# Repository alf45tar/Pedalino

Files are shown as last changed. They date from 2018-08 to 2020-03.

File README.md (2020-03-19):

# Pedalino™ has been superseed by [PedalinoMini™](https://github.com/alf45tar/PedalinoMini).

# Pedalino™ (discontinued)

_I know. You are thinking: "yet another MIDI controller with Arduino"._
_Pedalino™ is something new from any previous DIY projects and even better of commercial alternatives at a fraction of the cost._

>Right now the hardware is just a working well prototype. It will be boxed when the hardware will be frozen.

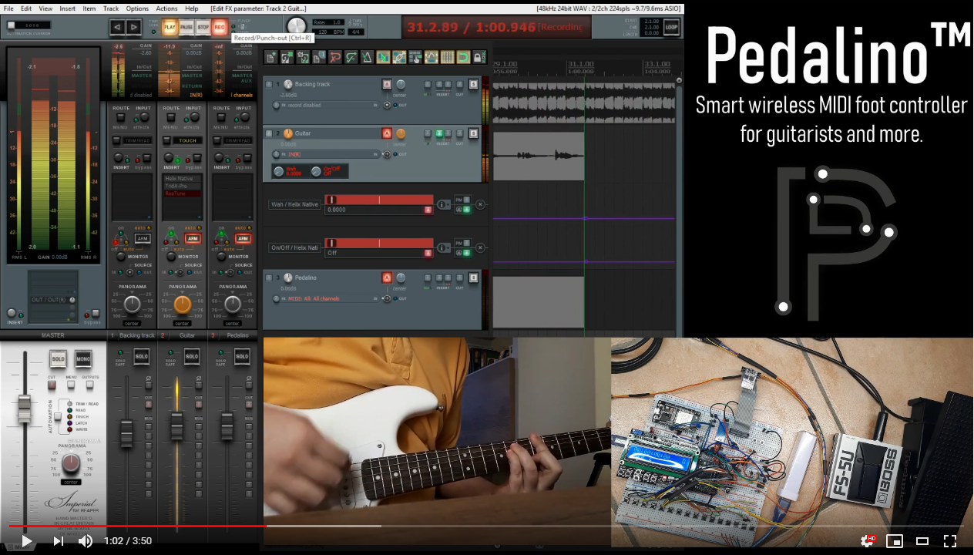
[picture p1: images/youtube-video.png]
(https://youtu.be/pCNSvJ9QiDs)


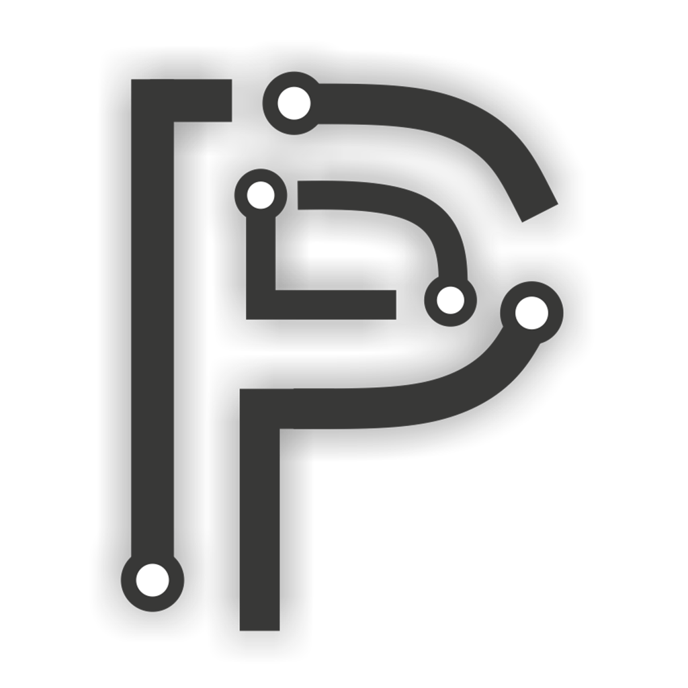
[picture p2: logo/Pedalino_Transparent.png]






Smart wireless MIDI foot controller for guitarists and more.

- Plug-and-play with any MIDI-compatible app on iOS 8 and above as well as OS X Yosemite and above.
- High customizable using iOS or Android app
- 4 MIDI interface (USB, Bluetooth, WiFi, legacy DIN MIDI IN and MIDI OUT connectors)
- No extra drivers to connect Windows, macOS, iOS (iPad/iPhone) and Android
- USB MIDI class-compliant device
- Bluetooth LE MIDI (iOS and macOS compatible)
- Network MIDI (aka AppleMIDI or RTP-MIDI)
- ipMIDI
- Open Sound Control (OSC)
- IEEE 802.11 b/g/n Wi-Fi 2.4 GHZ with WPA/WPA2 authentication
- Bluetooth Low Energy 4.0
- MIDI routing from/to any interface (USB, Bluetooth, WiFi, legacy)
- MIDI clock master and slave
- MIDI Time Code (MTC) master and slave
- OSC to MIDI and vicecersa
- Any number of pedals of any type in any order
- Auto-sensing footswitches and expression pedals
- Modular assembly of easy to find hardware and re-use of open source software libraries

## Applications

- Change preset to your favourite guitar rig
- Hands-free way to control your audio parameters during live performance
- Dramatically expanded audio system parameter control via WiFi, Bluetooth, USB, MIDI or OSC.
- Set your music free with wireless MIDI connectivity
- Bluetooth wireless MIDI adaptor for connecting instruments with MIDI IN/OUT terminals to your iOS devices (iPhone/iPad/iPod Touch) or Mac
- Transform legacy MIDI equipment to USB MIDI class-compliant device
- Transform wired MIDI equipment into wireless MIDI equipment
- Transform legacy MIDI equipment to OSC control surface
- Connect Windows to macOS and iOS devices via AppleMIDI or Bluetooth LE
- Send MIDI messages using an IR remote control from your sofa

## Features

- Support for digital foot switches (momentary or latch), analog expression pedals and jog wheels (rotary encoders)
- 10 banks of 16 controllers each
- 3 user configuration profiles
- Each port can connect 1 expression pedal or up to 3 foot switches for a maximum of 48 foot switches.
- MIDI output via USB MIDI, Bluetooth, classic MIDI OUT connector, AppleMIDI (also known as RTP-MIDI) or ipMIDI via Wi-Fi
- Send the following MIDI events: Program Change, Control Code, Note On/Off or Pitch Bend
- MIDI channel, MIDI note, MIDI control code, MIDI program change can be configured by each pedal and by each bank
- Switch debouncing and analog noise suppression without decreasing responsiveness
- Invert polarity via software
- Individual automatic calibration of expression pedals. Manual fine tuning is not usually requested.
- Transform a linear expression pedal into log expression pedal and vice versa
- Responsive and mobile-first configuration web interface (http://pedalino.local)
- Configuration via IR remote control
- Change bank via IR remote control
- Simulate footswitch push via IR remote control
- Use any spare IR remote control
- Smart Config technology to help users connect to a Wi-Fi network through simple app on a smartphone.
- Firmware update via HTTP (<http://pedalino.local/update>)

## iOS and Android App

The app made with [Blynk](https://www.blynk.cc) is on the way. Final version will be released later this year. Here some sneak preview images.

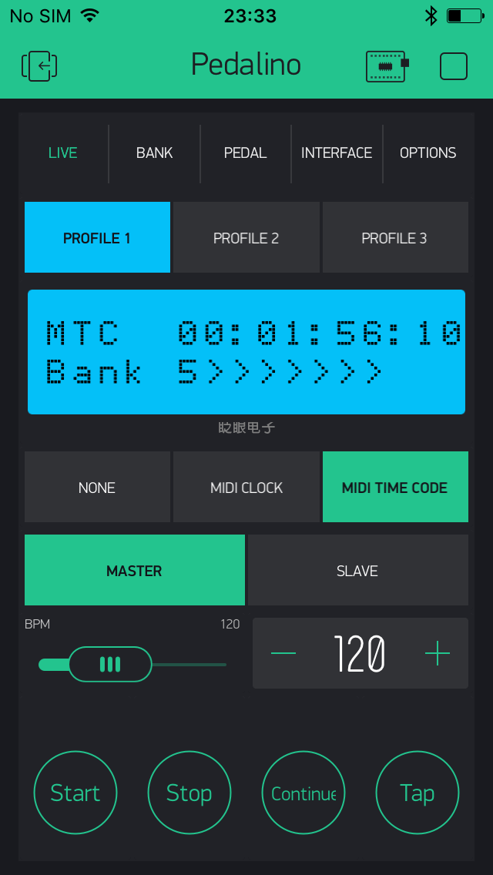
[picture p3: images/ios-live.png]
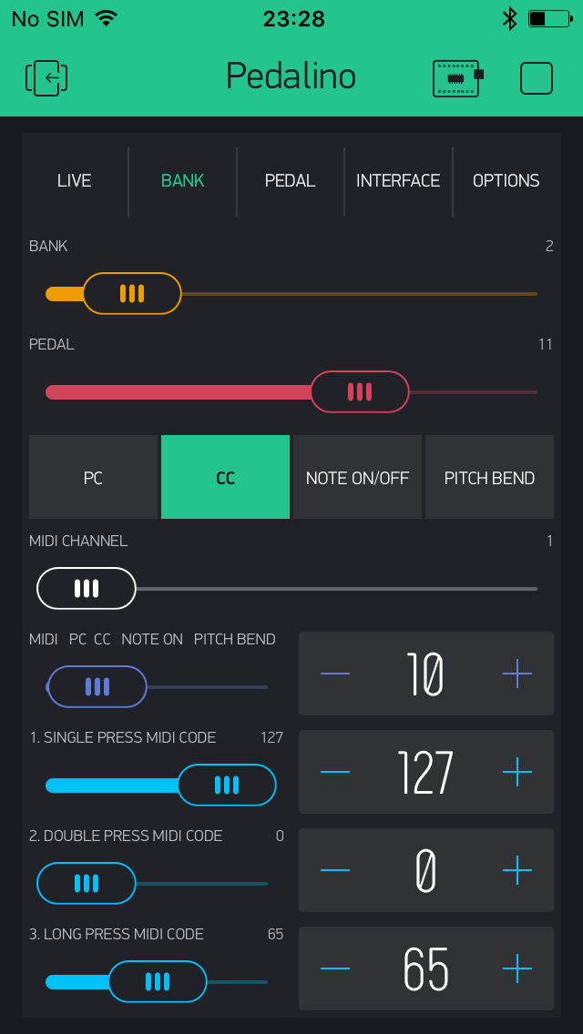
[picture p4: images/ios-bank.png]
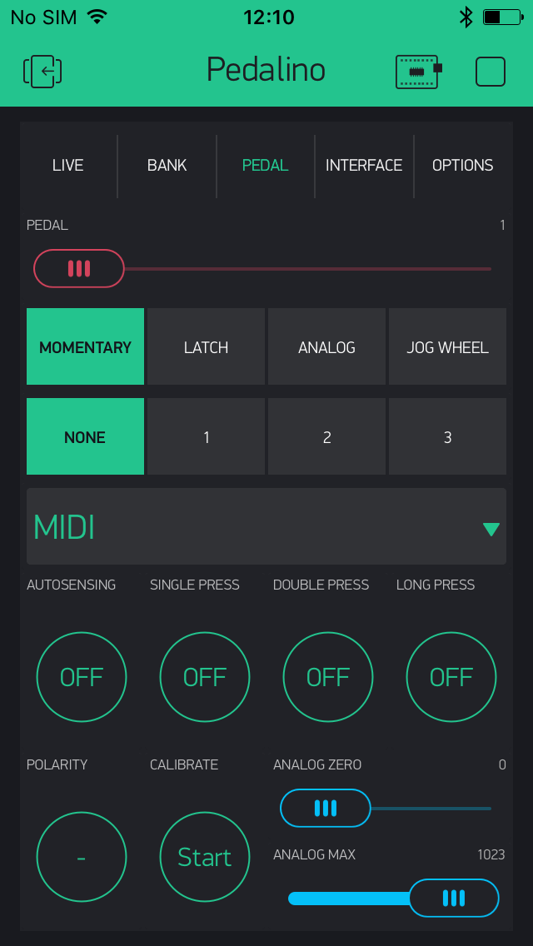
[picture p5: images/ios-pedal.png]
  

## Bill of materials

- Arduino Mega 2560 R3 or equivalent
- [LCD Keypad Shield](https://www.dfrobot.com/wiki/index.php/Arduino_LCD_KeyPad_Shield_(SKU:_DFR0009)) very popular 16x2 LCD based on the Hitachi HD44780 (or a compatible) chipset
- [New Liquid Crystal](https://bitbucket.org/fmalpartida/new-liquidcrystal/wiki/Home) library
- [Bounce2](https://github.com/thomasfredericks/Bounce2) library
- [ResponsiveAnalogRead](https://github.com/dxinteractive/ResponsiveAnalogRead) library
- [MD_Menu](https://github.com/MajicDesigns/MD_Menu) library
- [MD_UISwitch](https://github.com/MajicDesigns/MD_UISwitch) library
- [Arduino MIDI](https://github.com/FortySevenEffects/arduino_midi_library) library

The rest is not mandatory but it depends of which features you want to support.

- USB MIDI class-compliant device
  - [MocoLUFA](https://github.com/kuwatay/mocolufa) firmware
  
- MIDI IN interface
  - 6N137 Single-Channel High Speed Optocoupler (6N138 may works too)

- WIFI only (Model A)
  - Any ESP8266/ESP12 board supported by [Arduino core for ESP8266 WiFi chip](https://github.com/esp8266/Arduino) with a serial interface available. A development board provide direct USB connection and 5V compatibility.
  - Tested on [ESP8266 ESP-01S](https://en.wikipedia.org/wiki/ESP8266) 1M WiFi module and YL-46 AMS1117 3.3V Power Supply Module (Arduino 3.3V pin cannot provide enough current for the ESP-01S stable operation)
  - [Arduino core for ESP8266 WiFi chip](https://github.com/esp8266/Arduino)
  
- WIFI and Bluetooth MIDI (Model B)
  - Any ESP32 board supported by [Arduino core for ESP32 WiFi chip](https://github.com/espressif/arduino-esp32) with a serial interface available (usually Serial2 on standard development board because Serial is connected to USB and Serial1 cannot be connected during reset)
  - Tested on [DOIT ESP32 DevKit V1](https://github.com/SmartArduino/SZDOITWiKi/wiki/ESP8266---ESP32) 4M dual-mode Wi-Fi and Bluetooth module
  - [Arduino core for ESP32 WiFi chip](https://github.com/espressif/arduino-esp32)
  
- AppleMIDI via WIFI
  - [AppleMIDI for Arduino](https://github.com/lathoub/Arduino-AppleMIDI-Library) library
  
- OSC via WIFI
  - [CNMAT OSC for Arduino](https://github.com/CNMAT/OSC) library

- Infrared Remote Control
  - Any IR Receiver module (like KY-022 or equivalent) supported by [IRremote](https://github.com/z3t0/Arduino-IRremote) library
  - [IRremore](https://github.com/z3t0/Arduino-IRremote) library
  
- Bluetooth Remote Control
  - HM-10 (or compatible like HC-08) Bluetooth UART Communication Module

## Pedalino™ Breadboard Prototype

### MODEL A - WiFi only
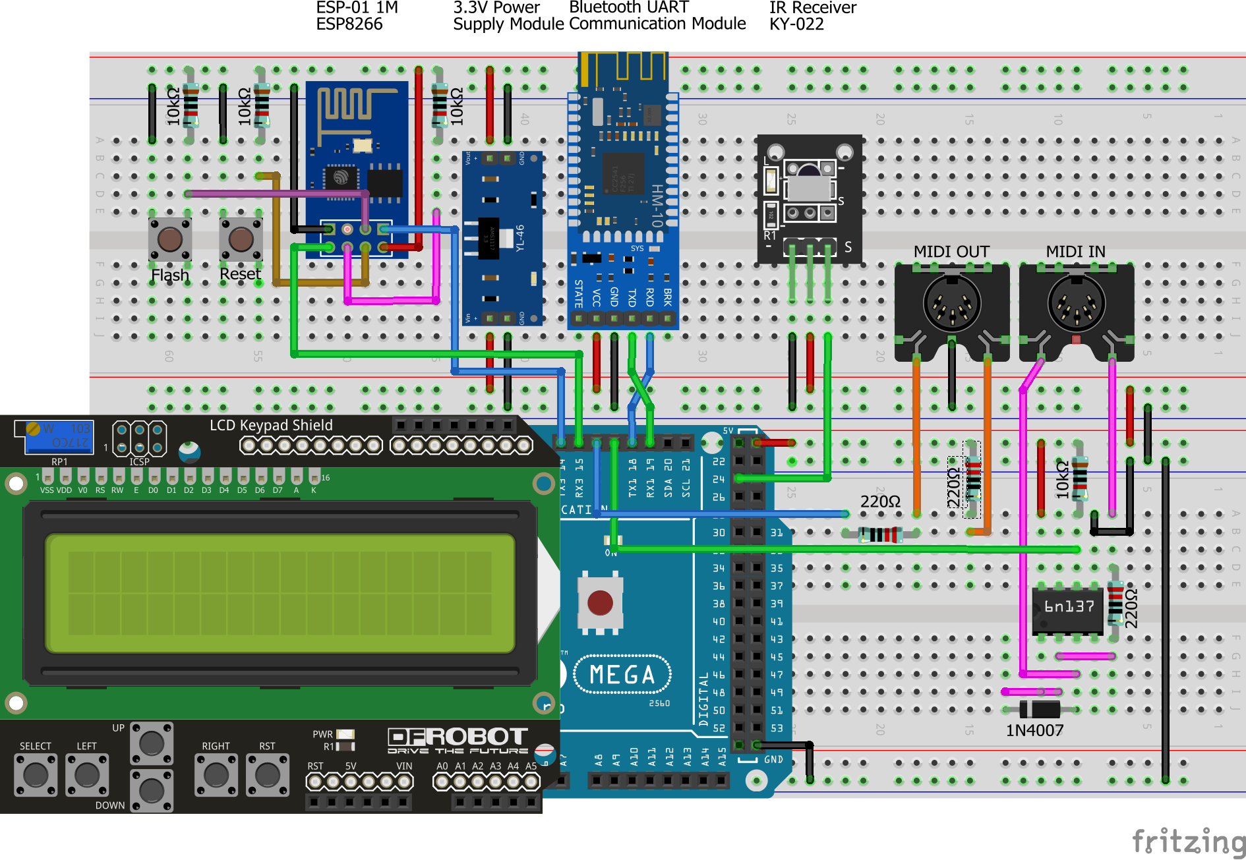
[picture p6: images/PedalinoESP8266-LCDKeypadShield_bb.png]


### MODEL B - WiFi and Bluetooth MIDI
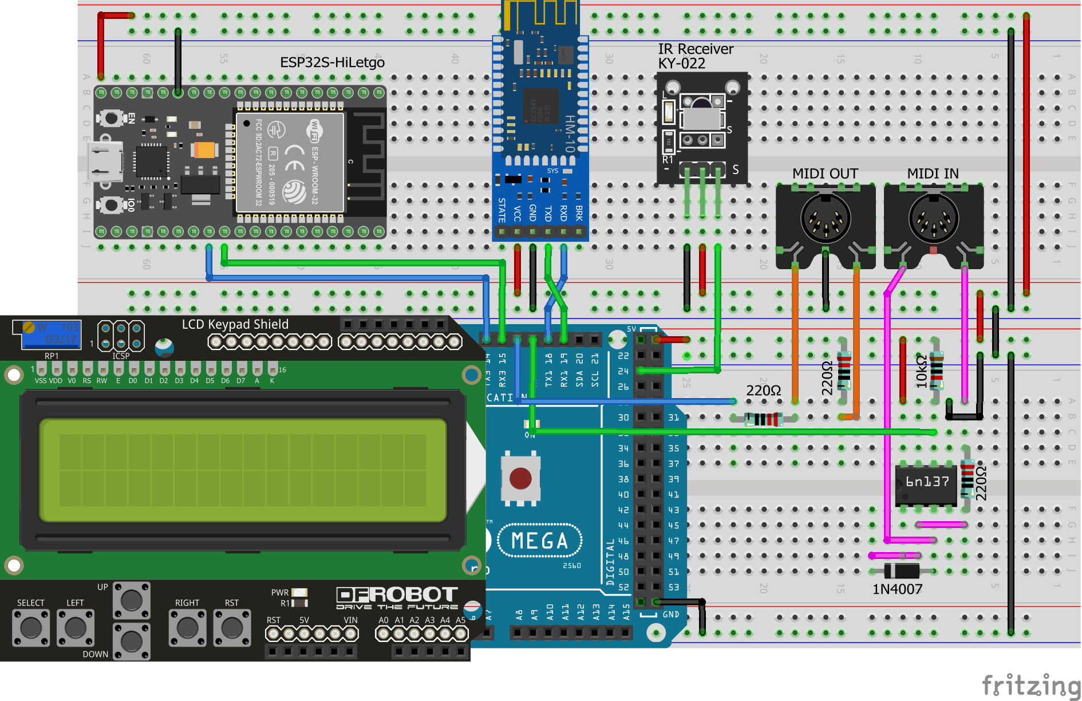
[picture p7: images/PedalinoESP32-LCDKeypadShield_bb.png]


Model A and B use HM-10 Bluetooth LE module to connect the app.

### MODEL C - Arduino UNO R3 + ESP8266 - WiFi only
Due to memory limit of Arduino Uno R3 some of the features cannot be supported. We eliminated the superfluous ones and kept the most interesting ones.

- All the interfaces (USB, Bluetooth, WiFi, legacy DIN MIDI IN and MIDI OUT connectors) and protocols (NetworkMIDI, IPMIDI and OSC) are supported
- 5 banks of 8 controllers each
- 3 profiles
- Configuration via web interface only
- No LCD
- No app
- No IR remote control

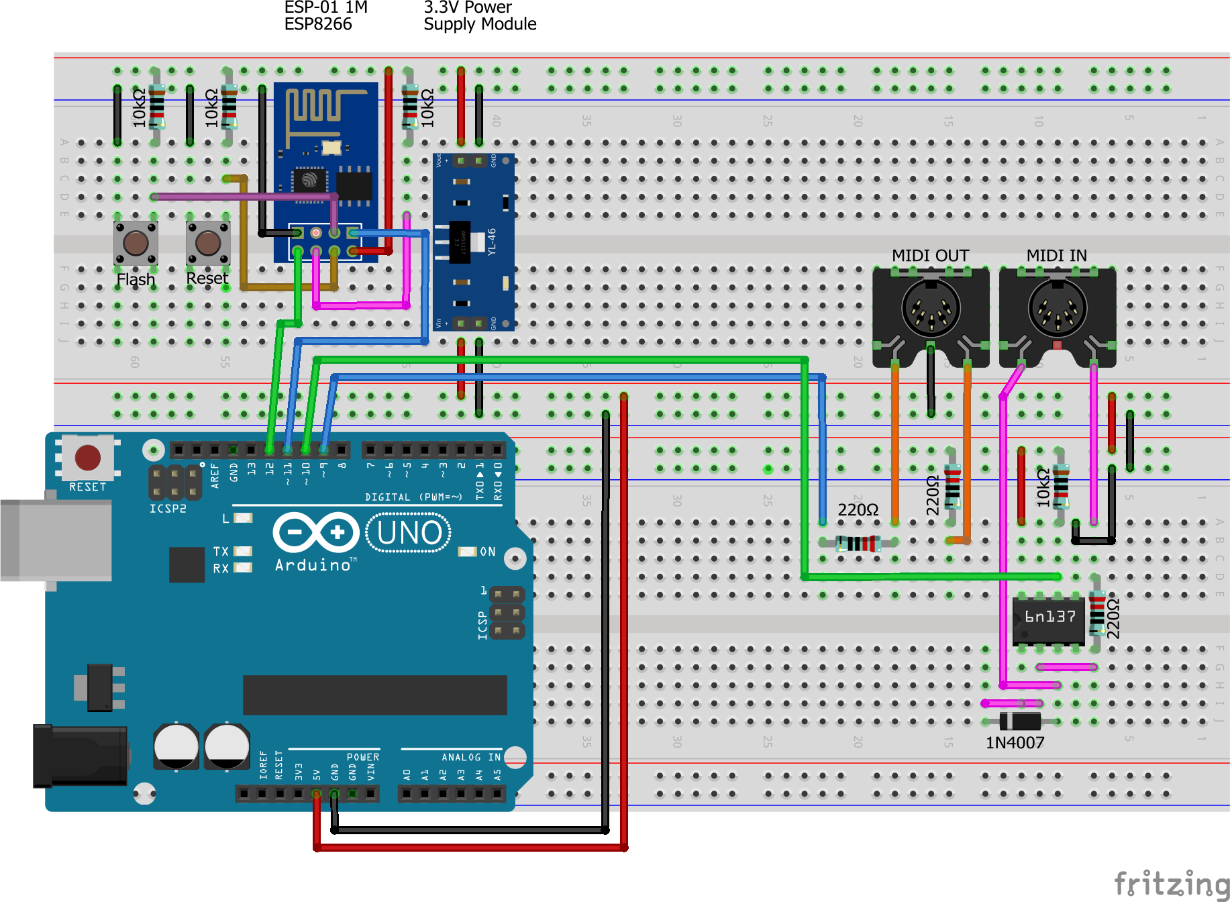
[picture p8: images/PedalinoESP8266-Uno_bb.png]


### First prototype
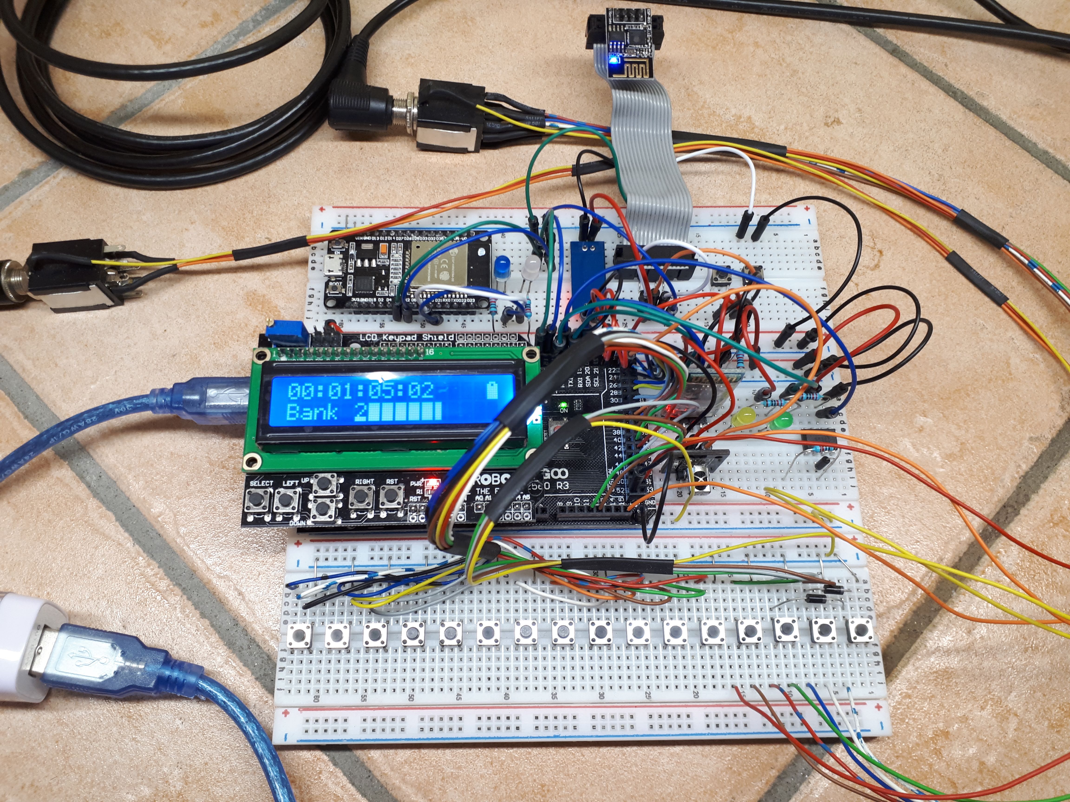
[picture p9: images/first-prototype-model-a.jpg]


## Firmware update

Pedalino is using 2 boards and 3 microcontrollers. All of them need to be flashed with the right firmware before using Pedalino.

Model|Board|Microcontroller|Firmware|Flashing software|Flashing hardware|Instructions
-----|-----|-----|-----|-----|-----|-----
Both|Arduino Mega 2560|ATmega2560<hr>ATmega16U2|[Pedalino](https://github.com/alf45tar/Pedalino/tree/master/src/avr)<hr>[MocoLUFA](https://github.com/kuwatay/mocolufa)|[Arduino IDE](https://www.arduino.cc/en/Main/Software)/[PlatformIO IDE](https://platformio.org/platformio-ide)<hr>[Atmel's flip programmer](http://www.microchip.com/developmenttools/productdetails.aspx?partno=flip)|None|[Click here](https://github.com/alf45tar/Pedalino/wiki/Build-and-upload-software)<hr>[Click here](https://www.arduino.cc/en/Hacking/DFUProgramming8U2) and [here](https://github.com/tttapa/MIDI_controller)
A|ESP-01S 1M|ESP8266|[PedalinoESP](https://github.com/alf45tar/Pedalino/tree/master/src/esp)|[Arduino IDE](https://www.arduino.cc/en/Main/Software)/[PlatformIO IDE](https://platformio.org/platformio-ide)|Arduino Mega|[Click here](https://github.com/alf45tar/Pedalino/wiki/How-to-flash-ESP8266-ESP%E2%80%9001S-WiFi-module)
B|DOIT ESP32 DevKit V1|ESP32|[PedalinoESP](https://github.com/alf45tar/Pedalino/tree/master/src/esp)|[Arduino IDE](https://www.arduino.cc/en/Main/Software)/[PlatformIO IDE](https://platformio.org/platformio-ide)|None|[Click here](https://github.com/alf45tar/Pedalino/wiki/Build-and-upload-software)

## Pedal Wiring

Pedalino is designed to work with the majority of expression pedals on the market, but there are a few popular pedal types which are incompatible and need to use adapters in order to work with Pedalino.

There is no recognized standard for footswitch and expression pedal inputs. Effects and amp manufacturers use whatever variations are appropriate for their particular application. This can cause problems for the consumer needing to find a footswitch or an expression pedal that will work well with particular devices.

Pedals connector is usually a 1/4" TRS jack. Each stereo TRS socket should be connected as follow.

Pedal|TIP - Digital Pin|RING - Analog Pin|SLEEVE - Ground
-----|-----|-----|-----
1|23|A0|GND
2|25|A1|GND
3|27|A2|GND
4|29|A3|GND
5|31|A4|GND
6|33|A5|GND
7|35|A6|GND
8|37|A7|GND
9|39|A8|GND
10|41|A9|GND
11|43|A10|GND
12|45|A11|GND
13|47|A12|GND
14|49|A13|GND
15|52|A14|GND
16|53|A15|GND

## Foot switches

Pedalino supports the following wiring:

Switches per port|Connector|Wiring|Example
-----|-----|-----|-----
1|Mono 1/4" TS<br>TS|1 switch between T and S|[Boss FS-5U](https://www.boss.info/us/products/fs-5u_5l/)<br>[Boss FS-5L](https://www.boss.info/us/products/fs-5u_5l/)
2|Stereo 1/4" TRS<br>TRS|1<sup>st</sup> switch between T and S <br>2<sup>nd</sup> switch between R and S|[Boss FS-6](https://www.boss.info/us/products/fs-6/)<br>[Boss FS-7](https://www.boss.info/us/products/fs-7/)
3|Stereo 1/4" TRS<br>TRS|[3-Button Schematic](https://github.com/alf45tar/Pedalino/blob/master/images/trs3button.jpg)|[Digitech FS3X](https://digitech.com/en/products/fs3x-3-button-footswitch)
5|Stereo 1/4" TRS<br>TRS|[Voltage Ladder](https://github.com/alf45tar/Pedalino/blob/master/images/lcd_switch_ladder.png)|[LCD Keypad Shield](https://www.dfrobot.com/wiki/index.php/Arduino_LCD_KeyPad_Shield_(SKU:_DFR0009))

Momentary and latch type switches are supported.

Normally open (NO) and normally closed (NC) is always supported and configurable by software if your foot switch do not have a polarity switch.

## Expression pedals

An expression pedal is more or less a pot with a 1/4" TRS jack plug.

Most potentiometers have three connectors; Clockwise, Counter-clockwise, and Wiper. Amazingly, there are multiple different ways these can be wired, all achieving largely the same result, which means yet more variations for expression pedals. The most common expression pedal wiring is to connect the pot to a 1/4″ stereo (TRS) instrument jack as follows:

Standard|Connector|Wiring|Example
-----|-----|-----|-----
Roland|Stereo 1/4" TRS<br>TRS|CW —> Sleeve<br>Wiper —> Tip<br>CCW —> Ring|[Roland EV-5](https://www.roland.com/global/products/ev-5/)<br>[M-Audio EX-P](http://www.m-audio.com/products/view/ex-p) (switch in "M-Audio")
Yamaha|Stereo 1/4" TRS<br>TRS|CW —> Sleeve<br>Wiper —> Ring<br>CCW —> Tip|[Yamaha FC7](https://usa.yamaha.com/products/music_production/accessories/fc7/index.html)<br>[M-Audio EX-P](http://www.m-audio.com/products/view/ex-p) (switch in "Other")<br>Technics SZ-E1/SZ-E2

Using a pedal with incompatible wiring can result in limited range, jumping or notch like response, or the pedal just won’t function at all, so make sure you check the requirements.

### Calibration

Pedalino like some of the more sophisticated effects and controllers incorporate a calibration utility that can mitigate some of the issues with pot rotation. There is a software option that allows the user to match the device to a specific expression pedal. This involves moving the pedal between it’s maximum and minimum settings and the device measuring the result. It then sets it’s internal parameters so that it recognizes where the maximum and minimum settings are of that particular pedal. This can often resolve problems of limited range. It’s important to calibrate all expression pedals. If the pedal is ever replaced, even with the same model, calibration should be run again.

## Auto Sensing

Most of the foot switches and expression pedals are plug-and-play because Pedalino will recognize via auto-sensing feature.

Auto-sensing will also enable automatic calibration. After each power on cycle move the expression pedal to its full range and Pedalino will calibrate it. During the first full movement of the pedal MIDI events could be not precise because Pedalino is still learning the full range of the pedal.

## USB MIDI

An USB class-compliant MIDI firmware for Arduino Uno/Mega (ATmega16U2) is required for using USB MIDI. Pedalino is tested with mocoLUFA because it supports dual mode boot (USB-MIDI or Arduino-Serial) and high-speed mode (1 Mbps). HIDUINO can works with minimal changes.

More information can be obtained in the following links:

- [MIDI_Controller](https://github.com/tttapa/MIDI_controller)
- [MocoLUFA](https://github.com/kuwatay/mocolufa)
- [HIDUINO](https://github.com/ddiakopoulos/hiduino)

### mocoLUFA dual boot

mocoLUFA firmware boots in USB MIDI mode by default.

Arduino-Serial mode is required to upload a new sketch into main Arduino ATmega2560 microcontroller.

To enable Arduino-Serial, add a jumper to PIN 4 (MOSI PB2) and PIN6 (GND) on ICSP connector for ATmega16U2. Power on cycle is required to switch the firmware mode.

ArduinoSerialJumper

### mocoLUFA high speed mode

mocoLUFA default speed is 31.250 bps but an undocumented high speed mode is in the code. A jumper between PIN 1 (MISO) and PIN 3 (SCK) on ICSP connector for ATmega16U2 enable the 1 Mbps speed. Pedalino USB MIDI works at 1 Mbps (1.000.000 bps).

HighSpeedJumper

## How to connect Pedalino to a WiFi network

AppleMIDI, ipMIDI and Open Sound Control (OSC) protocol requires a network connection. Pedalino support IEEE 802.11 b/g/n WiFi with WPA/WPA2 authentication (only 2.4 GHz).

Pedalino implements Smart Config technology via [Espressif’s ESP-TOUCH protocol](https://www.espressif.com/en/products/software/esp-touch/overview) to help users connect embedded devices to a WiFi network through simple configuration on a smartphone.

Tested apps for configure SSID and password are:

- [ESP8266 SmartConfig](https://play.google.com/store/apps/details?id=com.cmmakerclub.iot.esptouch) for Android

- [SmartConfig](https://itunes.apple.com/us/app/smartconfig/id1233975749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) for iOS

Boot procedure

- On power on Pedalino will try to connect to the last know access point (double blinking led)
- If it cannot connect to the last used access point within 15 seconds it enters into Smart Config mode (slow blinking led)
- Start one of the tested apps to configure SSID and password
- If it doesn't receive any SSID and password during the next 30 seconds it switch to AP mode (led off)
- In AP mode Pedalino create a WiFi network called 'Pedalino' waiting connection from clients. No password required. Led is off until a client connect to AP.
- Led is on when Pedalino is connected to an AP or a client is connected to Pedalino AP.
- Led will start fast blinking when Pedalino is partecipating to an AppleMIDI session.
- Reboot Pedalino to restart the procedure.

You can reset the last know access point via _Options->WiFi Reset_ menu.

## MIDI Network - AppleMIDI - RTP-MIDI

RTP-MIDI (also known as AppleMIDI) is a protocol to transport MIDI messages within RTP (Real-time Protocol) packets over Ethernet and WiFi networks. It is completely open and free.

Pedalino is a session listener over WiFi. It does not support session initiation functionalities, which requires the use of an external session initiator on the network to open a RTP-MIDI session with the Pedalino. This session initiator can be a macOS computer (Audio MIDI Setup->MIDI Studio->MIDI Network Setup) or a Windows computer with the [RTP-MIDI driver](https://www.tobias-erichsen.de/software/rtpmidi.html), an app on your iOS device (for example [MIDI Network](http://audioapps.nl/app/MIDINetwork)) or an embedded RTP-MIDI device.

Pedalino is designed to be compatible with:

- macOS computer
- iOS devices
- [rtpMIDI](https://www.tobias-erichsen.de/software/rtpmidi.html) for Windows
- [mnet MIDIhub](https://www.humatic.de/htools/mnet/man.htm) for Windows

## ipMIDI

Pedalino can route MIDI over your Ethernet or WiFi network, using [ipMIDI](https://www.nerds.de/en/ipmidi.html) protocol to send and receive MIDI data between computers connected to your LAN.

Pedalino is designed to be compatible with:

- [ipMIDI](https://www.nerds.de/en/ipmidi.html) for Windows/macOS
- [mnet MIDIhub](https://www.humatic.de/htools/mnet/man.htm) for Windows/macOS
- [QmidiNet](https://qmidinet.sourceforge.io) for Linux
- [multimidicast](http://llg.cubic.org/tools/multimidicast) for Linux

I prefers [mnet MIDIhub](https://www.humatic.de/htools/mnet/man.htm) for both RTP-MIDI and ipMIDI protocols. It is free and it works very well under Windows.

## Open Sound Control (OSC)

[Open Sound Control (OSC)](http://opensoundcontrol.org/introduction-osc) is an open, transport-independent, message-based protocol developed for communication among computers, sound synthesizers, and other multimedia devices.
Although the OSC specification does not enforce any particular type of transport, OSC is nowadays mostly used over traditional
networks known as IP (Internet Protocol).

The OSC protocol uses the IP network to carry messages from a source to a destination. Sources of OSC messages are
usually called OSC Clients, and destinations OSC Servers.

Pedalino is both able to receive (as a server), and send to several destinations (as multiple clients).

UDP and TCP are network protocols used for communicating OSC messages between two devices. UDP is the most widely used at the moment.

Pedalino supports UDP protocol only for transmitting and receiving OSC messages because TCP has more latency than UDP.

Pedalino will listen for OSC messages on UDP port 8000 and broadcast OSC messages on UDP port 9000 on the same WiFi LAN segment it is connected.

### OSC namespace

OSC specification does not define any namespace. There is no de-facto standard too.

Pedalino OSC namespace for incoming and outcoming MIDI events is:

MIDI Event|OSC Address|OSC Arguments|Min|Max|Note
-----|-----|-----|-----|-----|-----
Note On|/pedalino/midi/note/#|float velocity<br>int channel|0<br>1|1<br>16|# is the MIDI note number 0..127
Note Off|/pedalino/midi/note/#|float velocity<br>int channel|0<br>1|0<br>16|# is the MIDI note number 0..127
Control Change|/pedalino/midi/cc/#|float value<br>int channel|0<br>1|1<br>16|# is the MIDI CC number 0..127
Program Change|/pedalino/midi/pc/#|int channel|1|16|# is the MIDI PC number 0..127
Pitch Bend|/pedalino/midi/pitchbend/#|float bend|0|1|# is the MIDI channel 1..16
After Touch Poly|/pedalino/midi/aftertouchpoly/#|float pressure|0|1|# is the MIDI note number 0..127
After Touch Chennel|/pedalino/midi/aftertouchchannel/#|float pressure|0|1|# is the MIDI channel 1..16
Song Position Pointer|/pedalino/midi/songposition/#|int beats|0|16383|# is song position in beats (1/16 note)
Song Select|/pedalino/midi/songselect/#|int number|0|127|# is song number 0..127
Tune Request|/pedalino/midi/tunerequest/||||
Start|/pedalino/midi/start/||||
Continue|/pedalino/midi/continue/||||
Stop|/pedalino/midi/stop/||||
Active Sensing|/pedalino/midi/activesensing/||||
Reset|/pedalino/midi/reset/||||

### OSC-to-MIDI and MIDI-to-OSC

Pedalino is able to converts incoming OSC messages to MIDI events and outgoing MIDI events to OSC messages.

The bottom line is you can connect MIDI devices (or software) that does not suport OSC natively with OSC enabled software (or device) without any hard to configure software bridge.

## Pedalino articles

- [These twenty projects won the Musical Instrument Challenge in the Hackaday Prize](https://hackaday.com/2018/10/16/these-twenty-projects-won-the-musical-instrument-challenge-in-the-hackaday-prize/) by Brian Benchoff on [hackaday.com](https://hackaday.com/2018/10/16/these-twenty-projects-won-the-musical-instrument-challenge-in-the-hackaday-prize/)
- [Finally, an open source MIDI foot controller](https://hackaday.com/2018/10/21/finally-an-open-source-midi-foot-controller/) by Brian Benchoff on [hackaday.com](https://hackaday.com/2018/10/21/finally-an-open-source-midi-foot-controller/)
- [Pedalino: A smart, open source wireless MIDI foot controller for guitarists and more](https://blog.adafruit.com/2018/10/30/pedalino-a-smart-open-source-wireless-midi-foot-controller-for-guitarists-and-more/) by Mike Barela on [adafruit.com](https://blog.adafruit.com/2018/10/30/pedalino-a-smart-open-source-wireless-midi-foot-controller-for-guitarists-and-more/)
- [Pedalino open source wireless MIDI foot controller with iOS and Android app](https://www.geeky-gadgets.com/pedalino-open-source-wireless-midi-foot-controller-31-10-2018/) by Julian Horsey on [geeky-gadgets.com](https://www.geeky-gadgets.com/pedalino-open-source-wireless-midi-foot-controller-31-10-2018/)
- [Pedalino: Open Source Wireless MIDI Foot Controller](https://www.open-electronics.org/pedalino-open-source-wireless-midi-foot-controller/) by Luca Ruggeri on [open-electronics.org](https://www.open-electronics.org/pedalino-open-source-wireless-midi-foot-controller/)

## Commercial alternatives

- [ControllerHub 8](https://ameliascompass.com/product/controllerhub-8/)
- [Audifront MIDI Expression](https://www.audiofront.net/MIDIExpression.php)
- [BomeBox](https://www.bome.com/products/bomebox)
- [iRig BlueBoard](http://www.ikmultimedia.com/products/irigblueboard)
- [Yamaha MD-BT01](https://usa.yamaha.com/products/music_production/accessories/md-bt01/index.html)

## ToDo

- [ ] Lite version for Arduino Uno R3
- [ ] Configuration web interface
- [ ] Build a plug&play network of interconnected Pedalino for MIDI routing
- [ ] Pedalino Mini (only USB and WiFi)
- [ ] Add rotary encoders
- [ ] User guide

## Copyright

Copyright 2017-2018 alf45tar

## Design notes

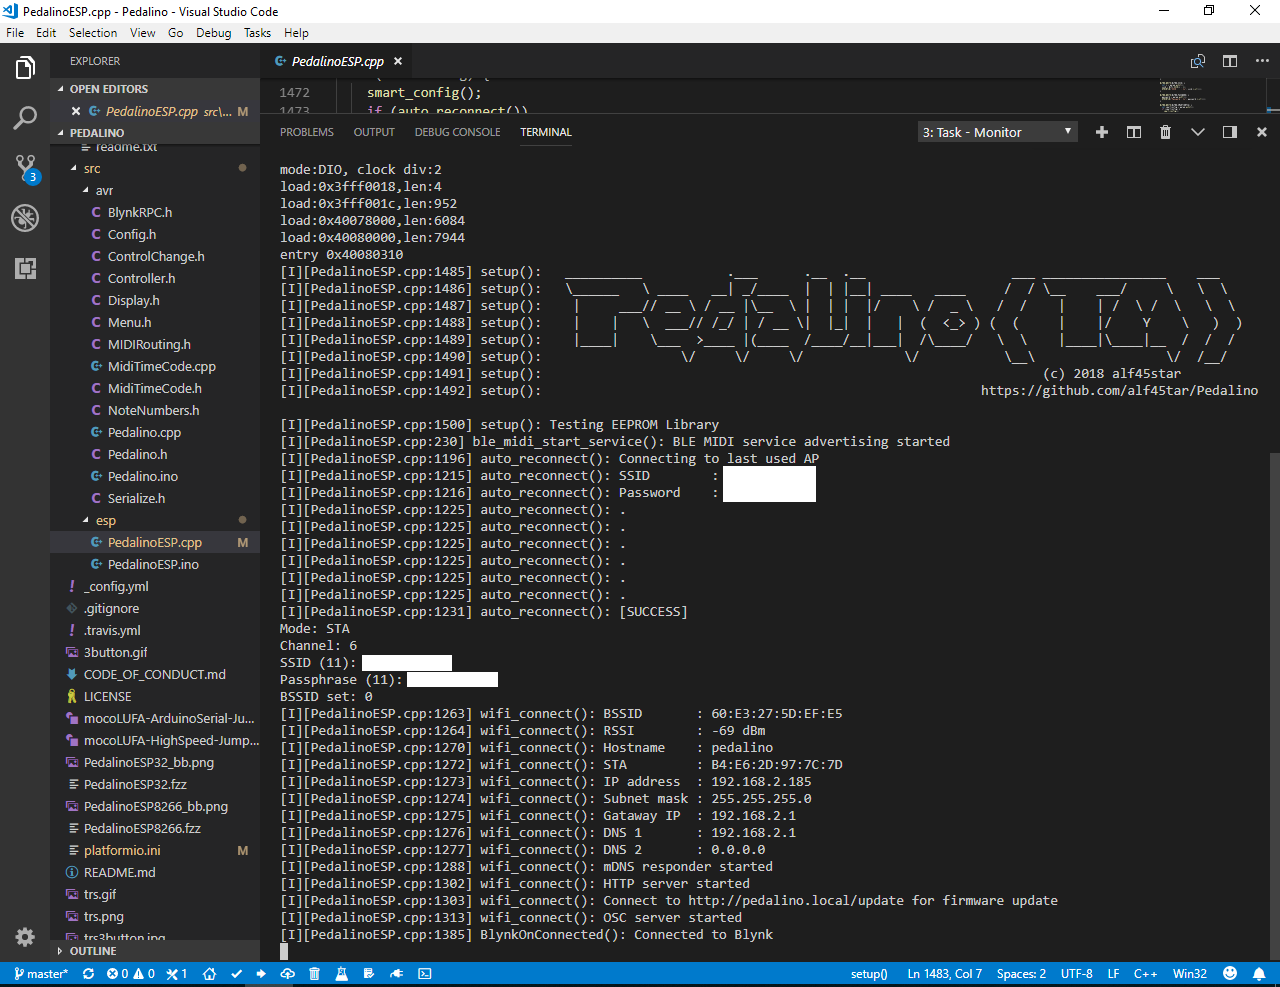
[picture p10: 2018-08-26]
images/PlatformIO.png

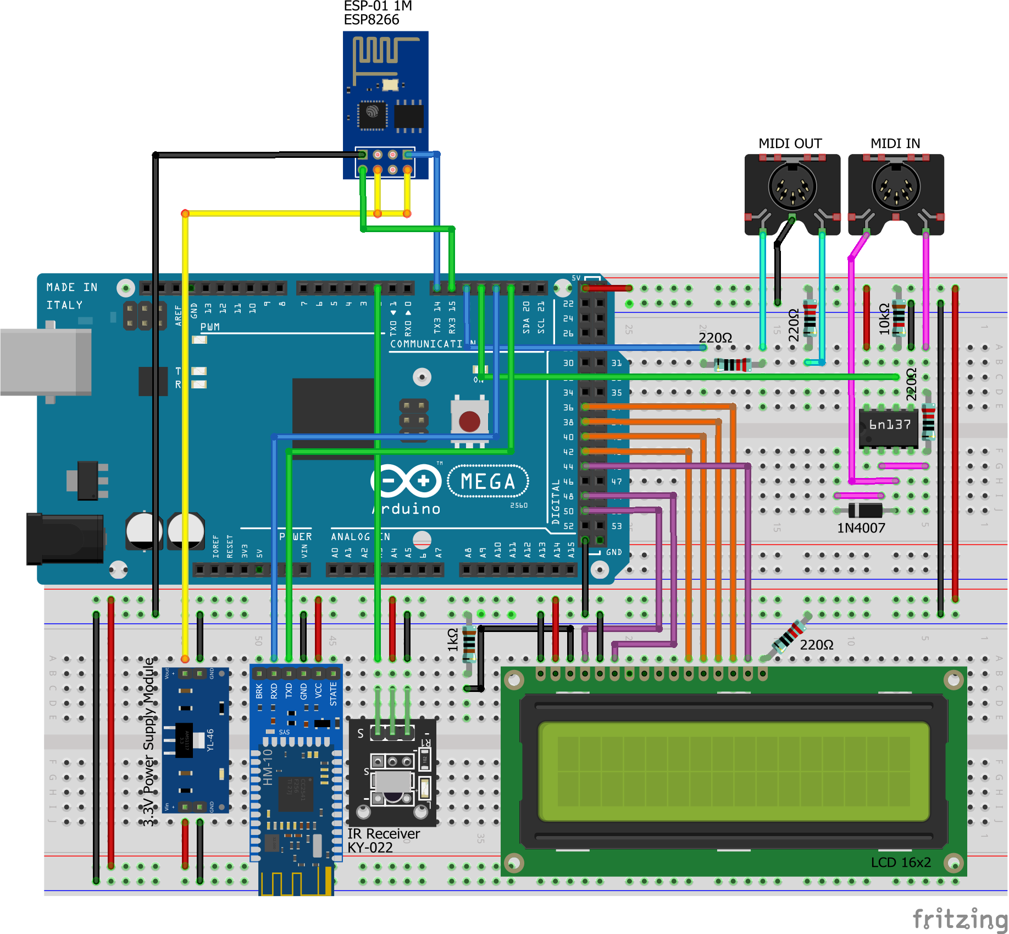
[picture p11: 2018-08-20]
images/PedalinoESP8266_bb.png

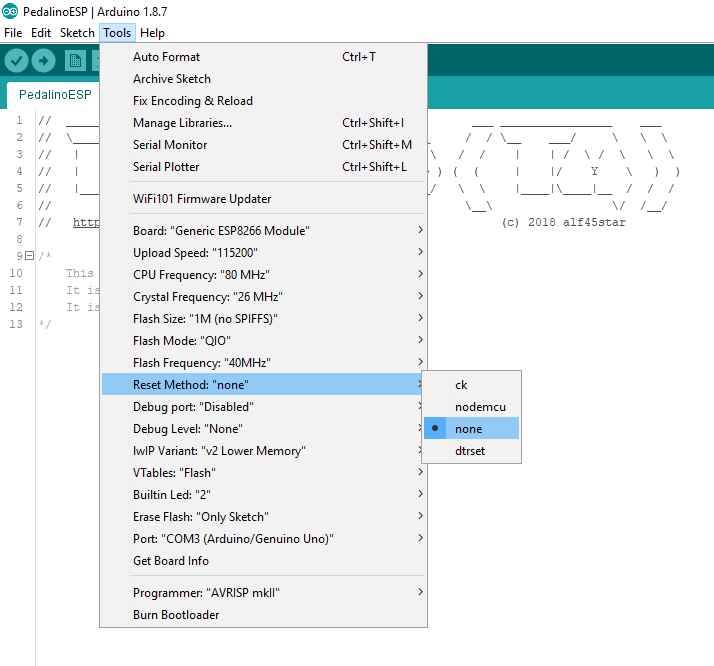
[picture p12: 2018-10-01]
images/arduino-ide-esp8266-flash-options.png

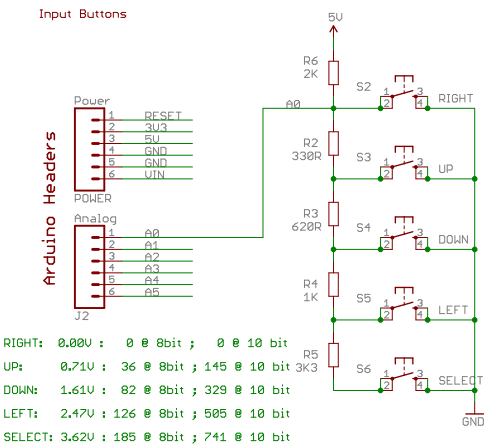
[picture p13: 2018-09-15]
images/lcd_switch_ladder.png

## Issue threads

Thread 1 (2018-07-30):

Display

cferrarini, 2018-07-30:
Hello friend

I would suggest you to use a display with i2c backpack, you can buy it apart, it uses only 2 wires.
Is it possible to use this library without the display? I want to make a simple minimalistic wired midi control for amplitube, with 5 momentary buttons and a bank switch to change 5 buttons between cc and pc, without bluetooth or wifi. Maybe a long press could change between cc and pc withou an extra button. Is it possible to do that?

alf45tar, 2018-07-30:
I will add support for I2C display. Not a big deal because I have to change just one line of code.

My code is not a library but the firmware running on Pedalino hardware. Pedalino can run without display but you cannot change any parameter. Without display you can modify configuration changing the code ( I can support you) or connect a display just for change configuration. The new configuration will be saved into EEPROM and restored during boot.

If you don't need bluetooth and wifi just do not connect ESP8266/ESP32 board. No changes to software is required.

Pedalino support single press, double press and long press but right now cannot mix CC and PC on the same pedal. For example single press can send a CC value1, double press can send CC value2 and long press CC value3. As alternative single press can send PC value1, double press PC value2, and long press PC value3.

Different pedals can send different MIDI messages (CC, PC, notes, pitch bend) of course.

If not clear let me know.

Regards

alf45tar, 2018-09-15:
I decided to move to the LCD Keypad Shield because it is very popular, cheap, easy to install and 5 buttons available.

Closed 2018-09-15.

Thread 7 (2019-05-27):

help me

gurnay1973, 2019-05-27:
Dear, I love this project and I would love to get to the video, but I see advances that I can not find in the sketch. There will be the possibility of uploading the update and also information on how to install the push button (such as push buttons momentary pedal). also sketches of connection of the trs and of the pedals of expression. I am a rookie and I would appreciate your help, please.

alf45tar, 2019-05-28:
Connect the push button between a digital pin and GND.
More info on https://github.com/alf45tar/Pedalino#pedal-wiring or schematic in PedalinoMini
https://github.com/alf45tar/PedalinoMini/blob/master/images/Schematic_PedalinoMini_Sheet-2.svg

Closed 2019-06-09.

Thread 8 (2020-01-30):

user guide ?

joma67, 2020-01-30:
Great project , did you already made a user guide or manual ( Pedalino )? Love to build it , but i am very new to this and some instructions how to operate it would be very usefull !

alf45tar, 2020-01-30:
Pedalino™ has been superseed by PedalinoMini™.
I suggest to have a look to PedalinoMini™. More features than Pedalino™ in a compact form.

Closed 2020-01-30.

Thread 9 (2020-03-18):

Wont work with current ArduinoJson (V6)

arduino12, 2020-03-18:
**Hi,**

**Amazing work!**

I had to change this [line](https://github.com/alf45tar/Pedalino/blob/master/platformio.ini#L37) to `ArduinoJson@5` so it can compile using pio as a quick fix!
Maybe upgrade to v6 with this [guide](https://arduinojson.org/v6/doc/upgrade)?

Arad :)

alf45tar, 2020-03-19:
Pedalino is discontinued and I will not support anymore.
Use PedalinoMini https://github.com/alf45tar/PedalinoMini. More feautures in a compact form.

Closed 2020-03-19.

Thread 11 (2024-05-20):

Pedalino Mini 4 MIDI connection

tybenz, 2024-05-20:
Is the pedalino mini a USB host? Can I power it with USB AND send USB midi out to control other devices?

If not, can you tell me how to connect a 3.5mm jack or 1/4 jack for TRS-MIDI?

Using the parts list from https://github.com/alf45tar/PedalinoMini-4

alf45tar, 2024-05-20:
It is not an USB host. Only USB client.
Yes, you can power from USB and control other USB devices but it need to be connected to an USB host.

alf45tar, 2024-05-20:
https://midi.org/updated-how-to-make-your-own-3-5mm-mini-stereo-trs-to-midi-5-pin-din-cables

tybenz, 2024-05-24:
Ok thank you!

Closed 2024-05-24.

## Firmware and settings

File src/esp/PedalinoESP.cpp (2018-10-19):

/*  __________           .___      .__  .__                   ___ ________________    ___
 *  \______   \ ____   __| _/____  |  | |__| ____   ____     /  / \__    ___/     \   \  \   
 *   |     ___// __ \ / __ |\__  \ |  | |  |/    \ /  _ \   /  /    |    | /  \ /  \   \  \  
 *   |    |   \  ___// /_/ | / __ \|  |_|  |   |  (  <_> ) (  (     |    |/    Y    \   )  )
 *   |____|    \___  >____ |(____  /____/__|___|  /\____/   \  \    |____|\____|__  /  /  /
 *                 \/     \/     \/             \/           \__\                 \/  /__/
 *                                                                (c) 2018 alf45star
 *                                                        https://github.com/alf45tar/Pedalino
 */

/*
    ESP8266/ESP32 MIDI Gateway between

      - Serial MIDI
      - WiFi AppleMIDI a.k.a. RTP-MIDI a.k.a. Network MIDI
      - ipMIDI
      - Bluetooth LE MIDI
      - WiFi OSC
*/

#include <Arduino.h>
#include <ArduinoJson.h>
#include <EEPROM.h>
#include <MIDI.h>

#ifdef ARDUINO_ARCH_ESP8266
#define NOBLE
#include <ESP8266WiFi.h>
#include <ESP8266WebServer.h>
#include <ESP8266mDNS.h>
#include <ESP8266LLMNR.h>
#include <ESP8266HTTPUpdateServer.h>

#ifdef BLYNK
#include <BlynkSimpleEsp8266.h>
#endif
#endif  // ARDUINO_ARCH_ESP8266

#ifdef ARDUINO_ARCH_ESP32
#include <esp_log.h>
#include <string>

#ifndef NOWIFI
#include <WiFi.h>
#include <ESPmDNS.h>
#endif

#ifndef NOBLE
#include <BLEDevice.h>
#include <BLEServer.h>
#include <BLEUtils.h>
#include <BLE2902.h>
#endif

#ifdef BLYNK
#include <BlynkSimpleEsp32.h>
#endif

#define NOWEBCONFIG   // temporary
#endif  // ARDUINO_ARCH_ESP32

#ifndef NOWIFI
#include <WiFiClient.h>
#include <WiFiUdp.h>

#include <AppleMidi.h>
#include <OSCMessage.h>
#include <OSCBundle.h>
#include <OSCData.h>
#endif

#ifdef PEDALINO_TELNET_DEBUG
#include <RemoteDebug.h>          // Remote debug over telnet - not recommended for production, only for development    
RemoteDebug Debug;
#endif

#define WIFI_CONNECT_TIMEOUT    10
#define SMART_CONFIG_TIMEOUT    30

#if defined(ARDUINO_ARCH_ESP8266) && defined(DEBUG_ESP_PORT)
#define SERIALDEBUG       DEBUG_ESP_PORT
#define DPRINT(...)       DEBUG_ESP_PORT.printf( __VA_ARGS__ )
#define DPRINTLN(...)     DEBUG_ESP_PORT.printf( __VA_ARGS__ ); DEBUG_ESP_PORT.println();
#endif

#ifdef ARDUINO_ARCH_ESP32
#define SERIALDEBUG       Serial
#define LOG_TAG           "PedalinoESP"
#define DPRINT(...)       ESP_LOGI(LOG_TAG, __VA_ARGS__)
#define DPRINTLN(...)     ESP_LOGI(LOG_TAG, __VA_ARGS__)
#endif

#ifdef PEDALINO_TELNET_DEBUG
#define DPRINT(...)       rdebugI(__VA_ARGS__)
#define DPRINTLN(...)     rdebugIln(__VA_ARGS__)
#endif

#ifdef ARDUINO_ARCH_ESP8266
#define BLE_LED_OFF()
#define BLE_LED_ON()
#define WIFI_LED       2      // Onboard LED on GPIO2 is shared with Serial1 TX
#define WIFI_LED_OFF() digitalWrite(WIFI_LED, HIGH)
#define WIFI_LED_ON()  digitalWrite(WIFI_LED, LOW)
#endif

#ifdef ARDUINO_ARCH_ESP32
#define BLE_LED         21
#define WIFI_LED        19
#define BLE_LED_OFF()   digitalWrite(BLE_LED, LOW)
#define BLE_LED_ON()    digitalWrite(BLE_LED, HIGH)
#define WIFI_LED_OFF()  digitalWrite(WIFI_LED, LOW)
#define WIFI_LED_ON()   digitalWrite(WIFI_LED, HIGH)
#endif

#ifndef LED_BUILTIN
#define LED_BUILTIN    2
#endif

#ifndef WIFI_LED
#define WIFI_LED        LED_BUILTIN  // onboard LED, used as status indicator
#endif

#ifndef BLE_LED
#define BLE_LED         LED_BUILTIN  // onboard LED, used as status indicator
#endif

#ifndef DPRINT
#define DPRINT(...)
#endif

#ifndef DPRINTLN
#define DPRINTLN(...)
#define DPRINTMIDI(...)
#else
#define DPRINTMIDI(...)   printMIDI(__VA_ARGS__)
#endif

const char host[]           = "pedalino";

#ifdef BLYNK
const char blynkAuthToken[] = "63c670c13d334b059b9dbc9a0b690f4b";
WidgetLCD  blynkLCD(V0);
#endif

#ifdef ARDUINO_ARCH_ESP8266
ESP8266WebServer        httpServer(80);
ESP8266HTTPUpdateServer httpUpdater;
#endif

// Bluetooth LE MIDI interface

#if defined(ARDUINO_ARCH_ESP32) && !defined(NOBLE)

#define MIDI_SERVICE_UUID        "03b80e5a-ede8-4b33-a751-6ce34ec4c700"
#define MIDI_CHARACTERISTIC_UUID "7772e5db-3868-4112-a1a9-f2669d106bf3"

BLEServer             *pServer;
BLEService            *pService;
BLEAdvertising        *pAdvertising;
BLECharacteristic     *pCharacteristic;
BLESecurity           *pSecurity;
#endif
bool                  bleMidiConnected = false;
unsigned long         bleLastOn        = 0;

// WiFi MIDI interface to comunicate with AppleMIDI/RTP-MDI devices

#ifndef NOWIFI
APPLEMIDI_CREATE_INSTANCE(WiFiUDP, AppleMIDI); // see definition in AppleMidi_Defs.h
#endif

bool          appleMidiConnected = false;
unsigned long wifiLastOn         = 0;

// Serial MIDI interface to comunicate with Arduino

#define SERIALMIDI_BAUD_RATE  115200

struct SerialMIDISettings : public midi::DefaultSettings
{
  static const long BaudRate = SERIALMIDI_BAUD_RATE;
};

#ifdef ARDUINO_ARCH_ESP8266
#define SerialMIDI            Serial
#endif

#ifdef ARDUINO_ARCH_ESP32
#define SERIALMIDI_RX         16
#define SERIALMIDI_TX         17
HardwareSerial                SerialMIDI(2);
#endif

MIDI_CREATE_CUSTOM_INSTANCE(HardwareSerial, SerialMIDI, MIDI, SerialMIDISettings);

// ipMIDI

#ifndef NOWIFI
WiFiUDP                 ipMIDI;
IPAddress               ipMIDImulticast(225, 0, 0, 37);
unsigned int            ipMIDIdestPort = 21928;
#endif

// WiFi OSC comunication

#ifndef NOWIFI
WiFiUDP                 oscUDP;                  // A UDP instance to let us send and receive packets over UDP
IPAddress               oscRemoteIp;             // remote IP of an external OSC device or broadcast address
const unsigned int      oscRemotePort = 9000;    // remote port of an external OSC device
const unsigned int      oscLocalPort = 8000;     // local port to listen for OSC packets (actually not used for sending)
OSCMessage              oscMsg;
#endif

// Interfaces

#define INTERFACES          6

#define PED_USBMIDI         0
#define PED_DINMIDI         1
#define PED_RTPMIDI         2
#define PED_IPMIDI          3
#define PED_BLEMIDI         4
#define PED_OSC             5

struct interface {
  char                   name[4];
  byte                   midiIn;          // 0 = disable, 1 = enable
  byte                   midiOut;         // 0 = disable, 1 = enable
  byte                   midiThru;        // 0 = disable, 1 = enable
  byte                   midiRouting;     // 0 = disable, 1 = enable
  byte                   midiClock;       // 0 = disable, 1 = enable
};

interface interfaces[INTERFACES] = { "USB", 1, 1, 0, 1, 0,
                                     "DIN", 1, 1, 0, 1, 0,
                                     "RTP", 1, 1, 0, 1, 0,
                                     "IP ", 1, 1, 0, 1, 0,
                                     "BLE", 1, 1, 0, 1, 0,                                     
                                     "OSC", 1, 1, 0, 1, 0 };   // Interfaces Setup


void wifi_connect();

void serialize_on() {

  StaticJsonBuffer<100> jsonBuffer;
  JsonObject& root = jsonBuffer.createObject();

  root["on"] = true;
  
  String jsonString;
  root.printTo(jsonString);
  DPRINTLN("%s", jsonString.c_str());
  MIDI.sendSysEx(jsonString.length(), (byte *)(jsonString.c_str()));
}

void serialize_wifi_status(bool status) {

  StaticJsonBuffer<100> jsonBuffer;
  JsonObject& root = jsonBuffer.createObject();

  root["wifi.connected"] = status;
  
  String jsonString;
  root.printTo(jsonString);
  DPRINTLN("%s", jsonString.c_str());
  MIDI.sendSysEx(jsonString.length(), (byte *)(jsonString.c_str()));
}

void serialize_ble_status(bool status) {

  StaticJsonBuffer<100> jsonBuffer;
  JsonObject& root = jsonBuffer.createObject();

  root["ble.connected"] = status;
  
  char jsonString[50];
  root.printTo(jsonString);
  DPRINTLN("%s", jsonString);
  MIDI.sendSysEx(strlen(jsonString), (byte *)jsonString);
}

void save_wifi_credentials(String ssid, String password)
{
#ifdef ARDUINO_ARCH_ESP32
  int address = 32;
  EEPROM.writeString(address, ssid);
  address += ssid.length() + 1;
  EEPROM.writeString(address, password);
  EEPROM.commit();
  DPRINTLN("WiFi credentials saved into EEPROM");
#endif
}

void printMIDI(const char *interface, midi::StatusByte status, const byte *data)
{
  midi::MidiType  type;
  midi::Channel   channel;
  byte            note, velocity, pressure, number, value;
  int             bend;
  unsigned int    beats;

    type    = MIDI.getTypeFromStatusByte(status);
    channel = MIDI.getChannelFromStatusByte(status);

    switch(type) {
     
      case midi::NoteOff:
        note     = data[0];
        velocity = data[1];
        DPRINTLN("Received from %s  NoteOff 0x%02X   Velocity 0x%02X   Channel %02d", interface, note, velocity, channel);
        break;

      case midi::NoteOn:
        note     = data[0];
        velocity = data[1];
        DPRINTLN("Received from %s  NoteOn  0x%02X   Velocity 0x%02X   Channel %02d", interface, note, velocity, channel);
        break;

      case midi::AfterTouchPoly:
        note     = data[0];
        pressure = data[1];
        DPRINTLN("Received from %s  AfterTouchPoly   Note 0x%02X   Pressure 0x%02X   Channel %02d", interface, note, pressure, channel);
        break;

      case midi::ControlChange:
        number  = data[0];
        value   = data[1];
        DPRINTLN("Received from %s  ControlChange 0x%02X   Value 0x%02X   Channel %02d", interface, number, value, channel);
        break;

      case midi::ProgramChange:
        number  = data[0];
        DPRINTLN("Received from %s  ProgramChange 0x%02X   Channel %02d", interface, number, channel);
        break;

      case midi::AfterTouchChannel:    
        pressure = data[0];
        DPRINTLN("Received from %s  AfterTouchChannel   Pressure 0x%02X   Channel %02d", interface, pressure, channel);
        break;

      case midi::PitchBend:
        bend = data[1] << 7 | data[0];
        DPRINTLN("Received from %s  PitchBend   Bend 0x%02X   Channel %02d", interface, bend, channel);
        break;

      case 0xf0:
        switch(status) {

          case midi::SystemExclusive:
            DPRINTLN("Received from %s  SystemExclusive 0x%02X", interface, data[0]);
            break;

          case midi::TimeCodeQuarterFrame:
            value = data[0];
            DPRINTLN("Received from %s  TimeCodeQuarterFrame 0x%02X", interface, value);
            break;

          case midi::SongPosition:
            beats = data[1] << 7 | data[0];
            DPRINTLN("Received from %s  SongPosition Beats 0x%04X", interface, beats);
            break;

          case midi::SongSelect:
            number = data[0];
            DPRINTLN("Received from %s  SongSelect 0x%02X", interface, number);
            break;

          case midi::TuneRequest:
            DPRINTLN("Received from %s  TuneRequest", interface);
            break;

          case midi::Clock:
            //DPRINTLN("Received from %s  Clock", interface);
            break;

          case midi::Start:
            DPRINTLN("Received from %s  Start", interface);
            break;
          
          case midi::Continue:
            DPRINTLN("Received from %s  Continue", interface);
            break;

          case midi::Stop:
            DPRINTLN("Received from %s  Stop", interface);
            break;

          case midi::ActiveSensing:
            DPRINTLN("Received from %s  ActiveSensing", interface);
            break;

          case midi::SystemReset:
            DPRINTLN("Received from %s  SystemReset", interface);
            break;
        }
        break;
      
      default:
        break;
    }
}

void printMIDI (const char *interface, const midi::MidiType type, const midi::Channel channel, const byte data1, const byte data2)
{ 
  midi::StatusByte  status;
  byte              data[2];

  status = type | ((channel - 1) & 0x0f);
  data[0] = data1;
  data[1] = data2;
  printMIDI(interface, status, data);
}

#ifdef NOBLE
#define BLEMidiReceive(...)
#define BLESendNoteOn(...)
#define BLESendNoteOff(...)
#define BLESendAfterTouchPoly(...)
#define BLESendControlChange(...)
#define BLESendProgramChange(...)
#define BLESendAfterTouch(...)
#define BLESendPitchBend(...)
#define BLESendSystemExclusive(...)
#define BLESendTimeCodeQuarterFrame(...)
#define BLESendSongPosition(...)
#define BLESendSongSelect(...)
#define BLESendTuneRequest(...)
#define BLESendClock(...)
#define BLESendStart(...)
#define BLESendContinue(...)
#define BLESendStop(...) {}
#define BLESendActiveSensing(...)
#define BLESendSystemReset(...)
#else
void BLEMidiReceive(uint8_t *, uint8_t);

class MyBLEServerCallbacks: public BLEServerCallbacks {
    void onConnect(BLEServer* pServer) {
      bleMidiConnected = true;
      serialize_ble_status(true);
      DPRINT("BLE client connected");
    };

    void onDisconnect(BLEServer* pServer) {
      bleMidiConnected = false;
      serialize_ble_status(false);
      DPRINT("BLE client disconnected");
    }
};

class MyBLECharateristicCallbacks: public BLECharacteristicCallbacks {
    void onWrite(BLECharacteristic *pCharacteristic) {
      std::string rxValue = pCharacteristic->getValue();
      if (rxValue.length() > 0)
        if (interfaces[PED_BLEMIDI].midiIn) {
          BLEMidiReceive((uint8_t *)(rxValue.c_str()), rxValue.length());
          DPRINT("BLE Received %2d bytes", rxValue.length());
        }        
    }
};

void ble_midi_start_service ()
{
  BLEDevice::init("Pedal");
  pServer = BLEDevice::createServer();
  pServer->setCallbacks(new MyBLEServerCallbacks());

  pService = pServer->createService(MIDI_SERVICE_UUID);
  pCharacteristic = pService->createCharacteristic(MIDI_CHARACTERISTIC_UUID,
                    BLECharacteristic::PROPERTY_READ   |
                    BLECharacteristic::PROPERTY_NOTIFY |
                    BLECharacteristic::PROPERTY_WRITE_NR);

  pCharacteristic->setCallbacks(new MyBLECharateristicCallbacks());

  pCharacteristic->addDescriptor(new BLE2902());
  pService->start();

  pAdvertising = pServer->getAdvertising();
  pAdvertising->addServiceUUID(pService->getUUID());
  pAdvertising->start();

  pSecurity = new BLESecurity();
  pSecurity->setAuthenticationMode(ESP_LE_AUTH_REQ_SC_BOND);
}

void BLEMidiTimestamp (uint8_t *header, uint8_t *timestamp)
{
  /*
    The first byte of all BLE packets must be a header byte. This is followed by timestamp bytes and MIDI messages.

    Header Byte
      bit 7     Set to 1.
      bit 6     Set to 0. (Reserved for future use)
      bits 5-0  timestampHigh:Most significant 6 bits of timestamp information.
    The header byte contains the topmost 6 bits of timing information for MIDI events in the BLE
    packet. The remaining 7 bits of timing information for individual MIDI messages encoded in a
    packet is expressed by timestamp bytes.
    Timestamp Byte
    bit 7       Set to 1.
    bits 6-0    timestampLow: Least Significant 7 bits of timestamp information.
    The 13-bit timestamp for the first MIDI message in a packet is calculated using 6 bits from the
    header byte and 7 bits from the timestamp byte.
    Timestamps are 13-bit values in milliseconds, and therefore the maximum value is 8,191 ms.
    Timestamps must be issued by the sender in a monotonically increasing fashion.
    timestampHigh is initially set using the lower 6 bits from the header byte while the timestampLow is
    formed of the lower 7 bits from the timestamp byte. Should the timestamp value of a subsequent
    MIDI message in the same packet overflow/wrap (i.e., the timestampLow is smaller than a
    preceding timestampLow), the receiver is responsible for tracking this by incrementing the
    timestampHigh by one (the incremented value is not transmitted, only understood as a result of the
    overflow condition).
    In practice, the time difference between MIDI messages in the same BLE packet should not span
    more than twice the connection interval. As a result, a maximum of one overflow/wrap may occur
    per BLE packet.
    Timestamps are in the sender’s clock domain and are not allowed to be scheduled in the future.
    Correlation between the receiver’s clock and the received timestamps must be performed to
    ensure accurate rendering of MIDI messages, and is not addressed in this document.
  */
  /*
    Calculating a Timestamp
    To calculate the timestamp, the built-in millis() is used.
    The BLE standard only specifies 13 bits worth of millisecond data though,
    so it’s bitwise anded with 0x1FFF for an ever repeating cycle of 13 bits.
    This is done right after a MIDI message is detected. It’s split into a 6 upper bits, 7 lower bits,
    and the MSB of both bytes are set to indicate that this is a header byte.
    Both bytes are placed into the first two position of an array in preparation for a MIDI message.
  */
  unsigned long currentTimeStamp = millis() & 0x01FFF;

  *header = ((currentTimeStamp >> 7) & 0x3F) | 0x80;        // 6 bits plus MSB
  *timestamp = (currentTimeStamp & 0x7F) | 0x80;            // 7 bits plus MSB
}


// Decodes the BLE characteristics and calls MIDI.send if the packet contains sendable MIDI data
// https://learn.sparkfun.com/tutorials/midi-ble-tutorial
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
void loop()
{
  if (!appleMidiConnected) WIFI_LED_OFF();
  if (!bleMidiConnected)  BLE_LED_OFF();
  if (appleMidiConnected ||  bleMidiConnected) {
    // led fast blinking (5 times per second)
    if (millis() - wifiLastOn > 200) {
      if (bleMidiConnected) BLE_LED_ON();
      if (appleMidiConnected) WIFI_LED_ON();
      wifiLastOn = millis();
    }
    else if (millis() - wifiLastOn > 100) {
      BLE_LED_OFF();
      WIFI_LED_OFF();
    }
  }
#ifndef NOWIFI
  else
    // led always on if connected to an AP or one or more client connected the the internal AP
    switch (WiFi.getMode()) {
      case WIFI_STA:
        WiFi.isConnected() ? WIFI_LED_ON() : WIFI_LED_OFF();
        break;
      case WIFI_AP:
        WiFi.softAPgetStationNum() > 0 ? WIFI_LED_ON() : WIFI_LED_OFF();
        break;
      default:
        WIFI_LED_OFF();
        break;
    }
#endif

  // Listen to incoming messages from Arduino
  if (MIDI.read())
    DPRINTMIDI("Serial MIDI", MIDI.getType(), MIDI.getChannel(), MIDI.getData1(), MIDI.getData2());

  // Listen to incoming AppleMIDI messages from WiFi
  rtpMIDI_listen();

  // Listen to incoming ipMIDI messages from WiFi
  ipMIDI_listen();

  // Listen to incoming OSC UDP messages from WiFi
  oscUDP_listen();

#ifdef ARDUINO_ARCH_ESP8266
  // Run HTTP Updater
  httpServer.handleClient();
#endif

#ifdef BLYNK
  if (WiFi.isConnected())
    Blynk.run();
#endif

#ifdef PEDALINO_TELNET_DEBUG
  // Remote debug over telnet
  Debug.handle();
#endif
}

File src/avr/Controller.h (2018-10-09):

/*  __________           .___      .__  .__                   ___ ________________    ___
 *  \______   \ ____   __| _/____  |  | |__| ____   ____     /  / \__    ___/     \   \  \   
 *   |     ___// __ \ / __ |\__  \ |  | |  |/    \ /  _ \   /  /    |    | /  \ /  \   \  \  
 *   |    |   \  ___// /_/ | / __ \|  |_|  |   |  (  <_> ) (  (     |    |/    Y    \   )  )
 *   |____|    \___  >____ |(____  /____/__|___|  /\____/   \  \    |____|\____|__  /  /  /
 *                 \/     \/     \/             \/           \__\                 \/  /__/
 *                                                                (c) 2018 alf45star
 *                                                        https://github.com/alf45tar/Pedalino
 */


#ifdef NOLCD
#define screen_info(...)
#else
void screen_info(byte, byte, byte, byte);
#endif

//
//  Autosensing setup
//
void autosensing_setup()
{
  int tip;    // tip connected to an input digital pin 23, 25, ... 53 with internal pull-up resistor
  int ring;   // ring connected to an input analog pin A0, A1, ... A15
  /*        */// sleeve connected to GND
  int ring_min;
  int ring_max;
  Bounce debouncer;

  return;

  DPRINTLNF("Pedal autosensing...");

  for (byte p = 0; p < PEDALS; p++) {
    pinMode(PIN_D(p), INPUT_PULLUP);
    if (pedals[p].autoSensing) {
      debouncer.attach(PIN_D(p));
      debouncer.interval(DEBOUNCE_INTERVAL);
      debouncer.update();
      tip = debouncer.read();

      DPRINTF("Pedal ");
      if (p < 9) DPRINTF(" ");
      DPRINT(p + 1);
      DPRINTF("   Tip Pin ");
      DPRINT(PIN_D(p));
      DPRINTF(" ");
      switch (tip) {
        case LOW:
          DPRINTF("LOW ");
          break;
        case HIGH:
          DPRINTF("HIGH");
          break;
      }
      DPRINTF("    Ring Pin A");
      DPRINT(p);
      if (p < 10) DPRINTF(" ");
      DPRINTF(" ");

      ring_min = ADC_RESOLUTION;
      ring_max = 0;
      for (int i = 0; i < 10; i++) {
        ring = analogRead(PIN_A(p));
        ring_min = min(ring, ring_min);
        ring_max = max(ring, ring_max);

        DPRINT(ring);
        DPRINTF(" ");

      }
      if ((ring_max - ring_min) > 1) {
        if (tip == LOW) {
          // tip connected to GND
          // switch between tip and ring normally closed
          pedals[p].mode = PED_MOMENTARY1;
          pedals[p].invertPolarity = true;
          DPRINTLNF(" MOMENTARY POLARITY-");
        }
        else {
          // not connected
          pedals[p].mode = PED_MOMENTARY1;
          pedals[p].invertPolarity = false;
          DPRINTLNF(" FLOATING PIN - NOT CONNECTED ");
        }
      }
      else if (ring <= 1) {
        // ring connected to sleeve (GND)
        // switch between tip and ring
        pedals[p].mode = PED_MOMENTARY1;
        if (tip == LOW) pedals[p].invertPolarity = true; // switch normally closed
        DPRINTF(" MOMENTARY");
        if (pedals[p].invertPolarity) DPRINTF(" POLARITY-");
        DPRINTLNF("");
      }
      else if (ring > 0) {
        // analog
        pedals[p].mode = PED_ANALOG;
        pedals[p].invertPolarity = true;
        // inititalize continuos calibration
        pedals[p].expZero = ADC_RESOLUTION - 1;
        pedals[p].expMax = 0;
        DPRINTLNF(" ANALOG POLARITY-");
      }
    }
    else {
      DPRINTF("Pedal ");
      if (p < 9) DPRINTF(" ");
      DPRINT(p + 1);
      DPRINTLNF("   autosensing disabled");
    }
  }
  DPRINTLNF("");
}

byte map_digital(byte p, byte value)
{
  p = constrain(p, 0, PEDALS - 1);
  return value;
}

unsigned int map_analog(byte p, unsigned int value)
{
  p = constrain(p, 0, PEDALS - 1);
  value = constrain(value, pedals[p].expZero, pedals[p].expMax);                  // make sure that the analog value is between the minimum and maximum value
  value = map(value, pedals[p].expZero, pedals[p].expMax, 0, ADC_RESOLUTION - 1); // map the value from [minimumValue, maximumValue] to [0, 1023]
  switch (pedals[p].mapFunction) {
    case PED_LINEAR:
      break;
    case PED_LOG:
      value = round(log(value + 1) * 147.61);             // y=log(x+1)/log(1023)*1023
      break;
    case PED_ANTILOG:
      value = round((exp(value / 511.5) - 1) * 160.12);   // y=[e^(2*x/1023)-1]/[e^2-1]*1023
      break;
  }
  return value;
}


void midi_send(byte message, byte code, byte value, byte channel, bool on_off = true )
{
  switch (message) {

    case PED_NOTE_ON_OFF:

      if (on_off && value > 0) {
#ifdef DEBUG_PEDALINO
        DPRINTF("     NOTE ON     Note ");
        DPRINT(code);
        DPRINTF("     Velocity ");
        DPRINT(value);
        DPRINTF("     Channel ");
        DPRINT(channel);
#else
        if (interfaces[PED_USBMIDI].midiOut)    USB_MIDI.sendNoteOn(code, value, channel);
#endif
        if (interfaces[PED_DINMIDI].midiOut)    DIN_MIDI.sendNoteOn(code, value, channel);
        if (interfaces[PED_RTPMIDI].midiOut ||
            interfaces[PED_IPMIDI].midiOut  ||
            interfaces[PED_BLEMIDI].midiOut ||
            interfaces[PED_OSC].midiOut)        ESP_MIDI.sendNoteOn(code, value, channel);
        screen_info(midi::NoteOn, code, value, channel);
      }
      else {
#ifdef DEBUG_PEDALINO
        DPRINTF("     NOTE OFF    Note ");
        DPRINT(code);
        DPRINTF("     Velocity ");
        DPRINT(value);
        DPRINTF("     Channel ");
        DPRINT(channel);
#else
        if (interfaces[PED_USBMIDI].midiOut)    USB_MIDI.sendNoteOff(code, value, channel);
#endif
        if (interfaces[PED_DINMIDI].midiOut)    DIN_MIDI.sendNoteOff(code, value, channel);
        if (interfaces[PED_RTPMIDI].midiOut ||
            interfaces[PED_IPMIDI].midiOut  ||
            interfaces[PED_BLEMIDI].midiOut ||
            interfaces[PED_OSC].midiOut)        ESP_MIDI.sendNoteOff(code, value, channel);
        screen_info(midi::NoteOff, code, value, channel);
      }
      break;

    case PED_CONTROL_CHANGE:

      if (on_off) {
#ifdef DEBUG_PEDALINO
        DPRINTF("     CONTROL CHANGE     Code ");
        DPRINT(code);
        DPRINTF("     Value ");
        DPRINT(value);
        DPRINTF("     Channel ");
        DPRINT(channel);
#else
        if (interfaces[PED_USBMIDI].midiOut)    USB_MIDI.sendControlChange(code, value, channel);
#endif
        if (interfaces[PED_DINMIDI].midiOut)    DIN_MIDI.sendControlChange(code, value, channel);
        if (interfaces[PED_RTPMIDI].midiOut ||
            interfaces[PED_IPMIDI].midiOut  ||
            interfaces[PED_BLEMIDI].midiOut ||
            interfaces[PED_OSC].midiOut)        ESP_MIDI.sendControlChange(code, value, channel);
        screen_info(midi::ControlChange, code, value, channel);
      }
      break;

    case PED_PROGRAM_CHANGE:
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

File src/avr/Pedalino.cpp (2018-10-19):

/*  __________           .___      .__  .__                   ___ ________________    ___
 *  \______   \ ____   __| _/____  |  | |__| ____   ____     /  / \__    ___/     \   \  \   
 *   |     ___// __ \ / __ |\__  \ |  | |  |/    \ /  _ \   /  /    |    | /  \ /  \   \  \  
 *   |    |   \  ___// /_/ | / __ \|  |_|  |   |  (  <_> ) (  (     |    |/    Y    \   )  )
 *   |____|    \___  >____ |(____  /____/__|___|  /\____/   \  \    |____|\____|__  /  /  /
 *                 \/     \/     \/             \/           \__\                 \/  /__/
 *                                                                (c) 2018 alf45star
 *                                                        https://github.com/alf45tar/Pedalino
 */

#include "Pedalino.h"
#include "Serialize.h"
#include "Controller.h"
#include "BlynkRPC.h"
#include "Config.h"
#include "MIDIRouting.h"
#include "Display.h"
#include "Menu.h"

void serial_pass_run()
{
  static bool startSerialPassthrough = true;
    
  if (startSerialPassthrough) {
#ifndef NOLCD
    lcd.clear();
    lcd.print(" USB to Serial ");
    lcd.setCursor(0, 1);
    lcd.print(" Reset to stop ");
#endif
    startSerialPassthrough = false;
  }

  if (Serial.available()) {         // If anything comes in Serial (USB),
    Serial3.write(Serial.read());   // read it and send it out Serial3
  }

  if (Serial3.available()) {        // If anything comes in Serial3
    Serial.write(Serial3.read());   // read it and send it out Serial (USB)
  }
}

// Standard setup() and loop()

void setup(void)
{
#ifdef DEBUG_PEDALINO
  SERIALDEBUG.begin(115200);

  DPRINTLNF("");
  DPRINTLNF("  __________           .___      .__  .__                   ___ ________________    ___");
  DPRINTLNF("  \\______   \\ ____   __| _/____  |  | |__| ____   ____     /  / \\__    ___/     \\   \\  \\");
  DPRINTLNF("   |     ___// __ \\ / __ |\\__  \\ |  | |  |/    \\ /  _ \\   /  /    |    | /  \\ /  \\   \\  \\");
  DPRINTLNF("   |    |   \\  ___// /_/ | / __ \\|  |_|  |   |  (  <_> ) (  (     |    |/    Y    \\   )  )");
  DPRINTLNF("   |____|    \\___  >____ |(____  /____/__|___|  /\\____/   \\  \\    |____|\\____|__  /  /  /");
  DPRINTLNF("                 \\/     \\/     \\/             \\/           \\__\\                 \\/  /__/");
  DPRINTLNF("                                                                (c) 2018 alf45star");
  DPRINTLNF("                                                        https://github.com/alf45tar/Pedalino");
  DPRINTLNF("");

#endif

  // Reset to factory default if RIGHT key is pressed and hold for alt least 8 seconds at power on
  // Enter serial passthrough mode if RIGHT key is pressed adn hold for less than 8 seconds at power on
  pinMode(A0, INPUT_PULLUP);
  unsigned long milliStart = millis();
  unsigned long duration = 0;
#ifndef NOLCD
    lcd.clear();
#endif 
  while ((digitalRead(A0) == LOW) && (duration < 8500)) {
    DPRINT("#");
#ifndef NOLCD
    lcd.setCursor(duration / 500, 0);
    lcd.print("#");
#endif
    delay(100);
    duration = millis() - milliStart;
  }
  DPRINTLN("");
  if ((digitalRead(A0) == HIGH) && (duration > 100 && duration < 8500)) {
    DPRINTLN("Serial passthrough mode for ESP firmware update and monitor");
    serialPassthrough = true;
  } else if ((digitalRead(A0) == LOW) && (duration >= 8500)) {
    DPRINTLN("Reset EEPROM to factory default");
#ifndef NOLCD
    lcd.setCursor(0, 1);
    lcd.print("Factory default ");
    delay(1000);
#endif
    load_factory_default();
    update_eeprom();
  }

  read_eeprom();

  // Initiate serial MIDI communications, listen to all channels and turn Thru off
#ifndef DEBUG_PEDALINO
  USB_MIDI.begin(MIDI_CHANNEL_OMNI);
  interfaces[PED_USBMIDI].midiThru ? USB_MIDI.turnThruOn() : USB_MIDI.turnThruOff();
#endif
  DIN_MIDI.begin(MIDI_CHANNEL_OMNI);
  interfaces[PED_DINMIDI].midiThru ? DIN_MIDI.turnThruOn() : DIN_MIDI.turnThruOff();
  ESP_MIDI.begin(MIDI_CHANNEL_OMNI);
  ESP_MIDI.turnThruOff();

  autosensing_setup();
  controller_setup();
  mtc_setup();
  midi_routing_start();
  blynk_config();
  menu_setup();
}

void loop(void)
{
  if (serialPassthrough) {
    serial_pass_run();
  }
  else {
    // Display menu on request
    menu_run();

    // Process Blynk messages
    blynk_run();

    // Check whether the input has changed since last time, if so, send the new value over MIDI
    midi_refresh();
    midi_routing();
  }
}

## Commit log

2018-07-15 Introducing ESP32 support
2018-08-08 Moved from Arduino IDE to PlatformIO IDE
2018-08-25 fixed a couple of compile warnings
    [MidiTimeCode.cpp]
2018-08-26 mDNS for ESP32 fixed
    [Menu.h, PedalinoESP.cpp]
2018-09-14 added LCD keypad shield
    [PedalinoESP32-LCDKeypadShield.fzz]
2018-09-15 Voltage ladder schematic
2018-09-15 support of voltage ladder for lcd keypad shield
2018-09-21 resut to factory default button
2018-09-23 fix backlight for lcd keypad shield
    [Pedalino.h]
2018-10-10 added Arduino Uno board
2018-10-19 fixed undercore for mDNS for ESP8266
    [PedalinoESP.cpp]
